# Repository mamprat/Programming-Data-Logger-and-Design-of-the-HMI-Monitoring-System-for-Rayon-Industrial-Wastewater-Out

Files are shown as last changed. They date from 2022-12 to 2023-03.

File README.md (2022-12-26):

# Programming-Data-Logger-and-Design-of-the-HMI-Monitoring-System-for-Rayon-Industrial-Wastewater-Out

Monitoring waste water outlets is used to reduce environmental pollution loads and reduce 
the impact on human health that is influenced by the environment, using wastewater quality 
parameters that match quality standards. This concept of monitoring aims to facilitate 
workers in an industry especially in the of Waste Water Treatment Plant or WWTP to 
determine the temperature, pH and total suspended solid or TSS levels in waste water 
outlets in the rayon industry. In the testing of this monitoring system, the actual waste outlet 
environment is not used, but the testing is done by modeling the waste outlet while using 
waste water material samples from the rayon industry. The linear regression approach is 
used to analyze TSS levels in wastewater outlets in the rayon industry using Arduino Mega 
as a controller used to detect these parameters. The management of data from the 
monitoring is then stored in the data logger device as the data resulted fron the monitoring 
by storing the data in the form of time and quality detection results in wastewater and is 
integrated with HMI Nextion devices as the display and as a sensor offset settings from 
outlet of wastewater. The results of this monitoring will make it easier for workers to 
analyze the condition of waste water outlets and take countermeasures so as to reduce the 
pollution burden and reduce the impact on human health.

Key words : Arduino Mega, Data logger, Hmi Nextion

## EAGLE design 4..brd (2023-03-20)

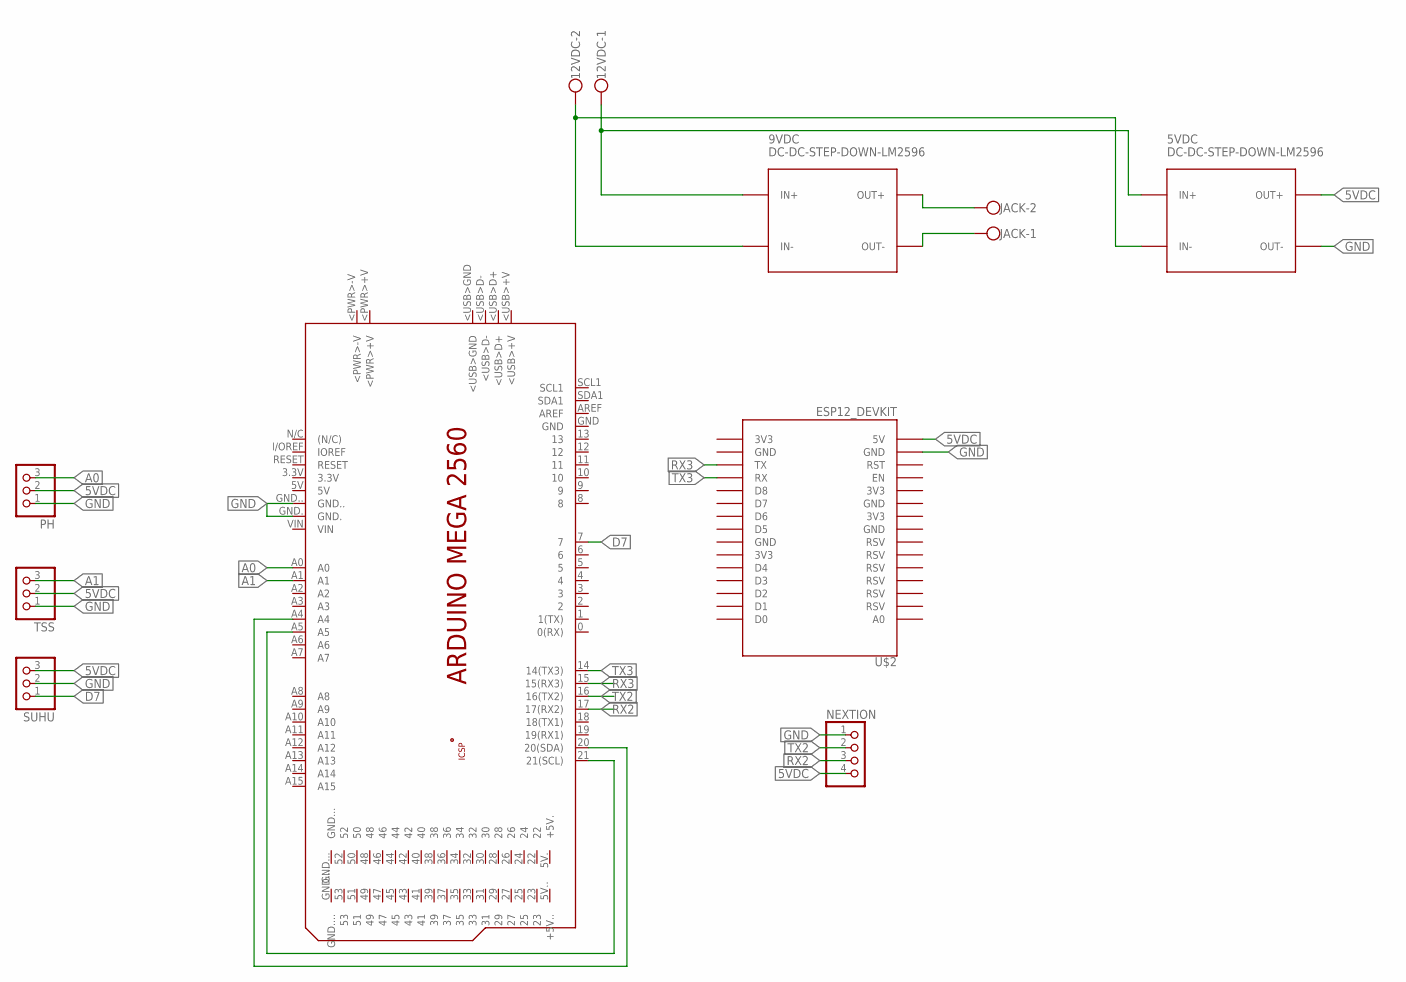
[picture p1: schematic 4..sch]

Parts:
5VDC, 9VDC: DC-DC-STEP-DOWN-LM2596
12VDC: W237-102
JACK: W237-102
NEXTION: PINHD-1X4; 1X04
PCB1: ARDUINO_MEGA2560
PH: PINHD-1X3; 1X03
SUHU: PINHD-1X3; 1X03
TSS: PINHD-1X3; 1X03
U$2: ESP12_DEVKIT

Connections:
5VDC: 5VDC.OUT+, NEXTION.4, PH.2, SUHU.3, TSS.2, U$2.5V
A0: PCB1.A0, PH.3
A1: PCB1.A1, TSS.3
D7: PCB1.7, SUHU.1
GND: 5VDC.OUT-, NEXTION.1, PCB1.GND., PCB1.GND.., PH.1, SUHU.2, TSS.1, U$2.GND@1 (GND)
unnamed: 5VDC.IN+, 9VDC.IN+, 12VDC.1
unnamed: 5VDC.IN-, 9VDC.IN-, 12VDC.2
unnamed: 9VDC.OUT+, JACK.2
unnamed: 9VDC.OUT-, JACK.1
unnamed: PCB1.20 (20(SDA)), PCB1.A4
unnamed: PCB1.21 (21(SCL)), PCB1.A5
RX2: NEXTION.3, PCB1.17 (17(RX2))
RX3: PCB1.15 (15(RX3)), U$2.TX
TX2: NEXTION.2, PCB1.16 (16(TX2))
TX3: PCB1.14 (14(TX3)), U$2.RX

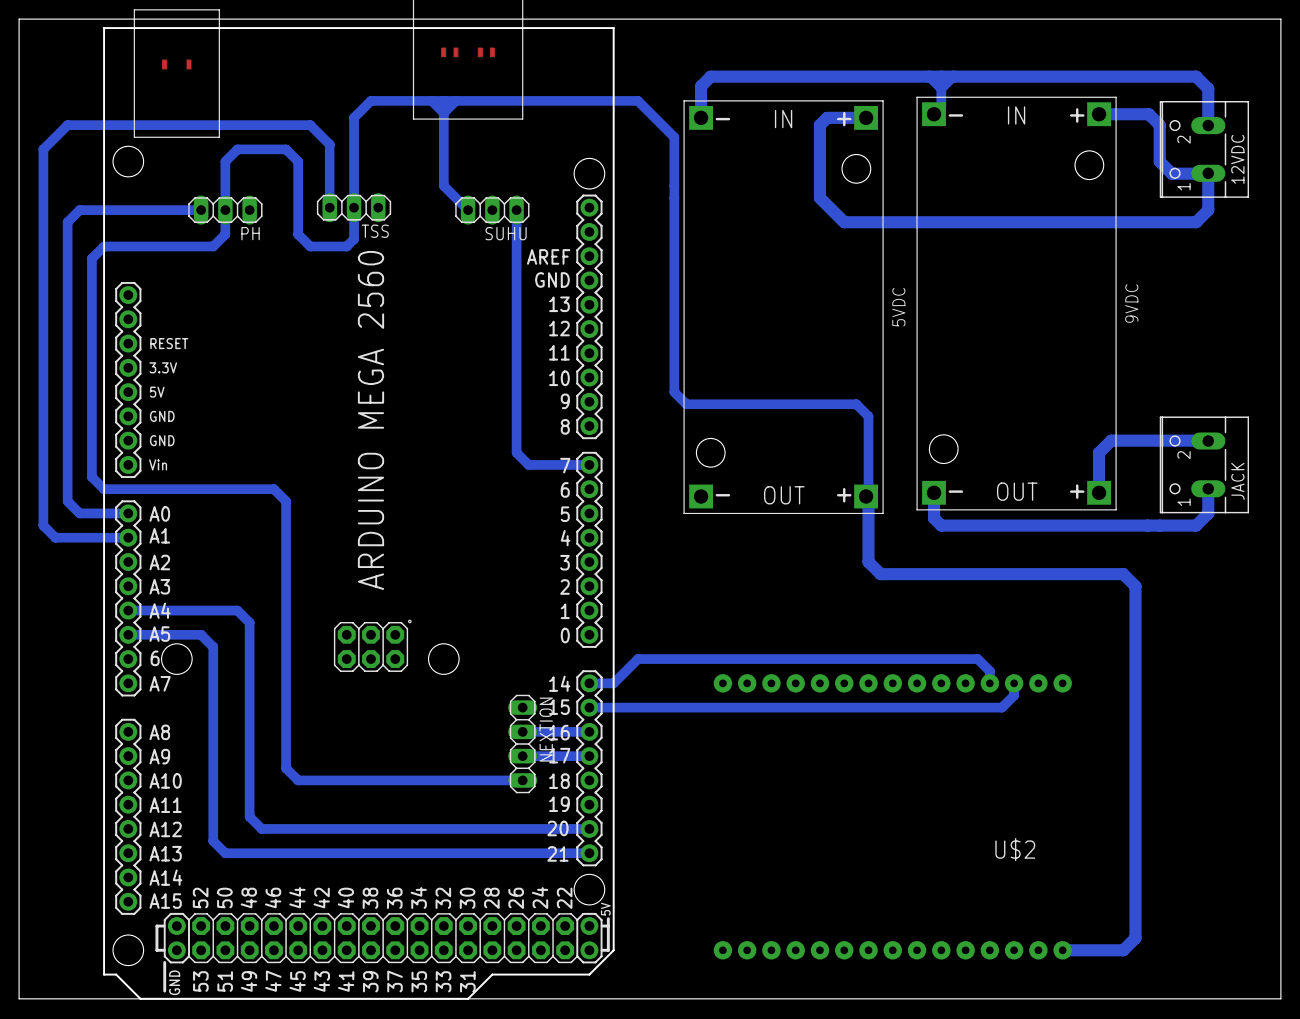
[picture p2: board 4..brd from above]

Board: 2 copper layers, 132.1 x 102.5 mm, 10 parts (0 on the bottom side), 15 nets.

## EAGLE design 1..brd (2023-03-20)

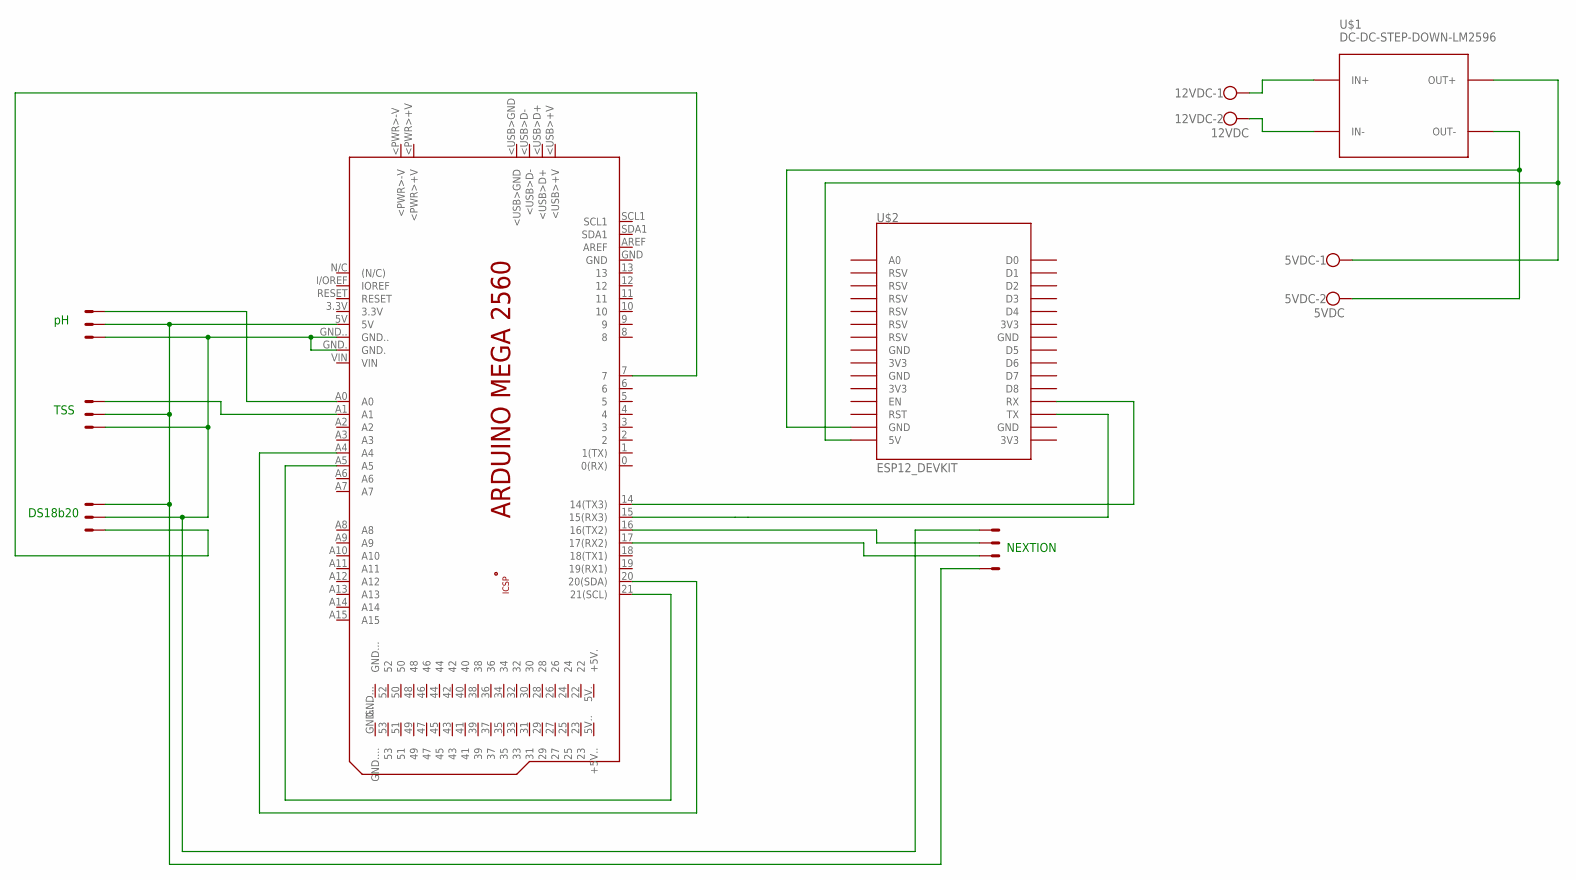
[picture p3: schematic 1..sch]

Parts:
5VDC: 5VDC; W237-102
12VDC: 12VDC; W237-102
A0: 22-23-2031
PCB1: ARDUINO_MEGA2560
U$1: DC-DC-STEP-DOWN-LM2596
U$2: ESP12_DEVKIT
X1: 22-23-2041
X2, X3: 22-23-2031

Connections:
unnamed: 12VDC.1, U$1.IN+
unnamed: 12VDC.2, U$1.IN-
unnamed: A0.1, PCB1.GND., PCB1.GND.., X1.1, X2.1, X3.2
unnamed: A0.2, PCB1.5V, X1.4, X2.2, X3.3
unnamed: A0.3, PCB1.A0
unnamed: PCB1.A1, X2.3
unnamed: PCB1.7, X3.1
unnamed: PCB1.20 (20(SDA)), PCB1.A4
unnamed: PCB1.21 (21(SCL)), PCB1.A5
unnamed: PCB1.14 (14(TX3)), U$2.RX
unnamed: PCB1.15 (15(RX3)), U$2.TX
unnamed: 5VDC.1, U$1.OUT+, U$2.5V
unnamed: 5VDC.2, U$1.OUT-, U$2.GND@1 (GND)
unnamed: PCB1.16 (16(TX2)), X1.2
unnamed: PCB1.17 (17(RX2)), X1.3

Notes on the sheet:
TSS
DS18b20
NEXTION

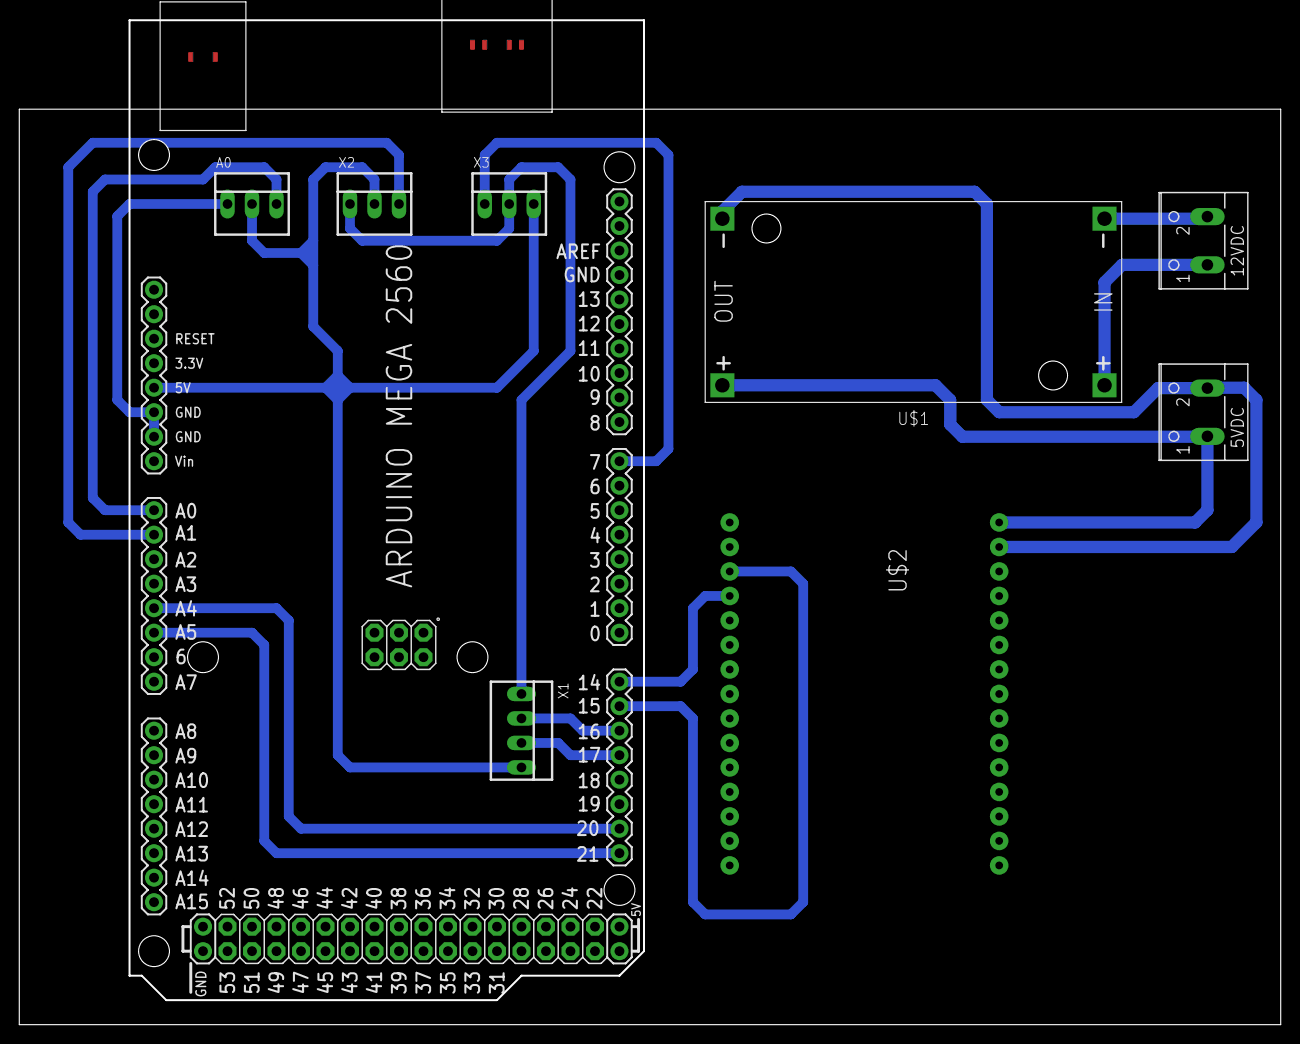
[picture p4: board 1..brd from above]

Board: 2 copper layers, 130.8 x 104.1 mm, 9 parts (0 on the bottom side), 15 nets.

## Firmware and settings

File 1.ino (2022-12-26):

#include <TimeLib.h>
#include <DS1307RTC.h>
#include <Wire.h>
#include <SPI.h>
#include <SD.h>
#include "Nextion.h"
#include <EEPROM.h>
#include <DallasTemperature.h>
#include <OneWire.h>
#include <SoftwareSerial.h>

#define ONE_WIRE_BUS 7
#define PH A0
#define samplingInterval 20
#define samplingInterval_1 20
#define samplingInterval_2 20
#define printInterval 800
#define ArrayLenth  40
#define interval 1000
#define interval1 1000

OneWire oneWire(ONE_WIRE_BUS);
DallasTemperature DS18B20(&oneWire);

const int chipSelect = 4; 

float Celsius;
float Offset_suhu;

int pHArray[ArrayLenth];
int pHArrayIndex = 0;
float Offset_ph;
static float pH;
static float teganganph;

int TSS = A1;
float tss;
float Offset_tss;
float tegangantss;

String data_string;
String txt_month;
String txt_day;
String txt_hour;
String txt_minute;
String txt_second;

static unsigned long time;
static unsigned long time_for_action;
static unsigned long time_for_action_1;
static unsigned long samplingTime = millis();
static unsigned long samplingTime_1 = millis();
static unsigned long samplingTime_2 = millis();
static unsigned long printTime_1 = millis();
unsigned long millis_string;
unsigned long millis_kirimdata;

File myFile;

NexButton s1 = NexButton(2, 3, "s1");
NexButton s2 = NexButton(2, 4, "s2");
NexButton p1 = NexButton(2, 6, "p1");
NexButton p2 = NexButton(2, 7, "p2");
NexButton t1 = NexButton(2, 9, "t1");
NexButton t2 = NexButton(2, 10, "t2");

char buffer[100] = {0};
NexTouch *nex_listen_list[] = {
  &s1,    &s2,  &p1,  &p2,  &t1,  &t2,
  NULL
};

void s2PushCallback(void *ptr) {
  Offset_suhu += 0.1;
  memset(buffer, 0, sizeof(buffer));
  itoa(Offset_suhu, buffer, 10);
  EEPROM.write(Offset_suhu, Celsius);
}

void s1PushCallback(void *ptr) {
  Offset_suhu -= 0.1;
  memset(buffer, 0, sizeof(buffer));
  itoa(Offset_suhu, buffer, 10);
  EEPROM.write(Offset_suhu, Celsius);
}

void p2PushCallback(void *ptr) {
  Offset_ph += 0.1;
  memset(buffer, 0, sizeof(buffer));
  itoa(Offset_ph, buffer, 10);
  EEPROM.write(Offset_ph, pH);
}

void p1PushCallback(void *ptr) {
  Offset_ph -= 0.1;
  memset(buffer, 0, sizeof(buffer));
  itoa(Offset_ph, buffer, 10);
  EEPROM.write(Offset_ph, pH);
}

void t2PushCallback(void *ptr) {
  Offset_tss += 0.1;
  memset(buffer, 0, sizeof(buffer));
  itoa(Offset_tss, buffer, 10);
  EEPROM.write(Offset_tss, tss);
}

void t1PushCallback(void *ptr) {
  Offset_tss -= 0.1;
  memset(buffer, 0, sizeof(buffer));
  itoa(Offset_tss, buffer, 10);
  EEPROM.write(Offset_tss, tss);
}

void setup() {
  Serial.begin(9600);
  Serial3.begin(9600);

  while (!Serial) ;
  setSyncProvider(RTC.get);
  if (timeStatus() != timeSet)
    Serial.println("Unable to sync with the RTC");
  else
    Serial.println("RTC has set the system time");
    
  if (!SD.begin(chipSelect)) {
  //if (!SD.begin(10, 11, 12, 13)) {              
    Serial.println("Gagal Membuka Micro SD!");
    return;
  }
  Serial.println("Berhasil Membuka Micro SD");

  DS18B20.begin();
  delay(2000);

  nexInit();
  s1.attachPush(s1PushCallback);
  s2.attachPush(s2PushCallback);
  p1.attachPush(p1PushCallback);
  p2.attachPush(p2PushCallback);
  t1.attachPush(t1PushCallback);
  t2.attachPush(t2PushCallback);

  time_for_action   = 0;
  time_for_action_1 = 0;

  millis_kirimdata  = 0;
}

void loop() {
  time = millis();
  if (millis () > time_for_action) {
    time_for_action = millis() + (unsigned long)interval;

    void loggingDS18B20();
    if (millis() - samplingTime > samplingInterval) {
      DS18B20.requestTemperatures();
      Celsius = (DS18B20.getTempCByIndex(0));
      String command = "displaysuhu.txt=\"" + String(Celsius + Offset_suhu) + "\"";
      Serial.print(command);
      Serial.write(0xff);
      Serial.write(0xff);
      Serial.write(0xff);
      samplingTime = millis();
    }

    void loggingPH();
    if (millis() - samplingTime_1 > samplingInterval_1) {
      pHArray[pHArrayIndex++] = analogRead(PH);
      if (pHArrayIndex == ArrayLenth)pHArrayIndex = 0;
      teganganph = (averageData() / 1023) * 5.0;
      pH = (3 * teganganph)- 0.10;
      String command = "displayph.txt=\"" + String(pH + Offset_ph) + "\"";
      Serial.print(command);
      Serial.write(0xff);
      Serial.write(0xff);
      Serial.write(0xff);
      samplingTime_1 = millis();
    }

    void loggingKEKERUHAN();
    if (millis() - samplingTime_2 > samplingInterval_2) {
      TSS = analogRead(A1);
      tegangantss = TSS * (5.0 / 1023.0);
      //tss = (-16.97 * tegangantss) + 69.29;//ntu
      //tss = (-5.839* tegangantss) + 45.43;//rayon
      tss = (-250.8* tegangantss) + 871.5;//tempe
      String command = "displaytss.txt=\"" + String(tss + Offset_tss) + "\"";
      Serial.print(command);
      Serial.write(0xff);
      Serial.write(0xff);
      Serial.write(0xff);
      samplingTime_2 = millis();
    }
  }

  if (millis () > time_for_action_1) {
    time_for_action_1 = millis() + (unsigned long)interval1;
    (timeStatus() == timeSet);
    myFile = SD.open ("logger.txt", FILE_WRITE);
    myFile.print(year());
    myFile.print("-");
    if (month() < 10) {
      txt_month = String("0") + month();
    }
    else {
      txt_month = String(month());
    }
    myFile.print(txt_month);
    myFile.print("-");
    if (day() < 10) {
      txt_day = String("0") + day();
    }
    else {
      txt_day = String(day());
    }
    myFile.print(txt_day );
    myFile.print(" ");
    if (hour() < 10) {
      txt_hour = String("0") + hour();
    }
    else {
      txt_hour = String(hour());
    }
    myFile.print(txt_hour);
    myFile.print(":");
    if (minute() < 10) {
      txt_minute = String("0") + minute();
    }
    else {
      txt_minute = String(minute());
    }
    myFile.print(txt_minute);
    myFile.print(':');
    if (second() < 10) {
      txt_second = String("0") + second();
    }
    else {
      txt_second = String(second());
    }
    myFile.print(txt_second);

    myFile.print(",");
    myFile.print(Celsius + Offset_suhu);
    myFile.print(",");
    myFile.print(pH + Offset_ph);
    myFile.print(",");
    myFile.print(tss + Offset_tss);
    myFile.println();
    myFile.close();
  }
  nexLoop(nex_listen_list);

  if (millis () - millis_string >= 250) {
    millis_string = millis();
    data_string =
      String (year())+ "," +
      String (txt_month)+ "," + 
      String (txt_day)+ "," + 
      String (txt_hour)+ "," + 
      String (txt_minute)+ "," + 
      String (txt_second)+ "," +
      String (Celsius + Offset_suhu) + "," +
      String (pH + Offset_ph) + "," +
      String (tss + Offset_tss);
  }

  if (millis() - millis_kirimdata >= 500) {
    millis_kirimdata = millis();
    Serial3.print(data_string);
    Serial3.print('\n');
  }
}

double averageData() {
  double temp = 0 ;
  for ( int i = 0 ; i < 500 ; i++ ) {
    temp += analogRead(A0);
  }
  return temp / 500 ;
}

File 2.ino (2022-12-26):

#include <Arduino.h>
#include <ESP8266WiFi.h>
#include <ESP8266WiFiMulti.h>
#include <ESP8266HTTPClient.h>
#include <Wire.h>
#include <SoftwareSerial.h>
#define USE_SERIAL Serial
SoftwareSerial NodeMcuRecv(D5, D6);

ESP8266WiFiMulti WiFiMulti;
HTTPClient http;

float celsius;
float ph;
float tss;

int year;
int txt_month;
int txt_day;
int txt_hour;
int txt_minute;
int txt_second;

String bulan;
String hari;
String jam;
String menit;
String detik;

String postData;
String data;

unsigned long millis_kirimdata = 0;

String url = "http://monitoringoutlet.com/inputsensor.php";
String var1 = "waktu=";
String var2 = "&celsius=";
String var3 = "&ph=";
String var4 = "&tss=";

void setup() {
  USE_SERIAL.begin(9600);
  NodeMcuRecv.begin(9600);
  USE_SERIAL.setDebugOutput(false);

  for (uint8_t t = 4; t > 0; t--) {
    //    USE_SERIAL.printf("[SETUP] Tunggu %d...\n", t);
    USE_SERIAL.flush();
    delay(500);
  }

  WiFi.mode(WIFI_STA);
  //WiFiMulti.addAP("AndroidAP1210", "bayarajadulu"); // Sesuaikan SSID dan password ini
  //  WiFiMulti.addAP("KoriqSquad", "GalonPecah11"); // Sesuaikan SSID dan password ini
  WiFiMulti.addAP("ECC", "Setandame");
}

void loop() {
  if ((WiFiMulti.run() == WL_CONNECTED)) {

    if (NodeMcuRecv.available()) {
      year = NodeMcuRecv.parseInt();
      txt_month = NodeMcuRecv.parseInt();
      bulan = String (txt_month);
      if (txt_month < 10) {
        bulan = String("0") + bulan;
      }

      txt_day = NodeMcuRecv.parseInt();
      hari = String (txt_day);
      if (txt_day < 10) {
        hari = String("0") + hari;
      }

      txt_hour = NodeMcuRecv.parseInt();
      jam = String (txt_hour);
      if (txt_hour < 10) {
        jam = String("0") + jam;
      }

      txt_minute = NodeMcuRecv.parseInt();
      menit = String (txt_minute);
      if (txt_minute < 10) {
        menit = String("0") + menit;
      }

      txt_second = NodeMcuRecv.parseInt();
      detik = String (txt_second);
      if (txt_second < 10) {
        detik = String("0") + detik;
      }

      celsius = NodeMcuRecv.parseFloat();
      ph = NodeMcuRecv.parseFloat();
      tss = NodeMcuRecv.parseFloat();

      if ((millis() - millis_kirimdata) >= 1000) {
        millis_kirimdata = millis();
        if (NodeMcuRecv.read() == '\n') {
          postData =
            var1 + (String) year + "-" +
            bulan + "-" +
            hari + " " +
            jam + ":" +
            menit + ":" +
            detik + " " +
            var2 + (String) celsius +
            var3 + (String) ph +
            var4 + (String) tss ;

          http.begin( url );
          http.addHeader("Content-Type", "application/x-www-form-urlencoded");

          int httpCode = http.POST(postData);
          USE_SERIAL.println(postData);
          http.end();
        }
      }
    }
  }
}

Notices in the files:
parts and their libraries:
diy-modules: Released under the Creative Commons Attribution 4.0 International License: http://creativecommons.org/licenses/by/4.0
